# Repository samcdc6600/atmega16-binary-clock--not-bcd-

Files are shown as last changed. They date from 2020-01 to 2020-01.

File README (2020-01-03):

Note that the file "m16Adef.inc" is not of my own creation and the licensing of
this project does not apply to it. I am not aware of what it's license is.

We assemble simply by issuing the following command (where x.asm is the name of
our assembly file):
    avra x.asm
    
We flash our micro with the following command (this is assumming our flasher's
device file is ugen0.2 and hello.hex is the output of avra that we are
interested in):
   doas avrdude -p m16 -c usbasp -P/dev/ugen0.2 -U flash:w:hello.hex

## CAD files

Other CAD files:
main.obj

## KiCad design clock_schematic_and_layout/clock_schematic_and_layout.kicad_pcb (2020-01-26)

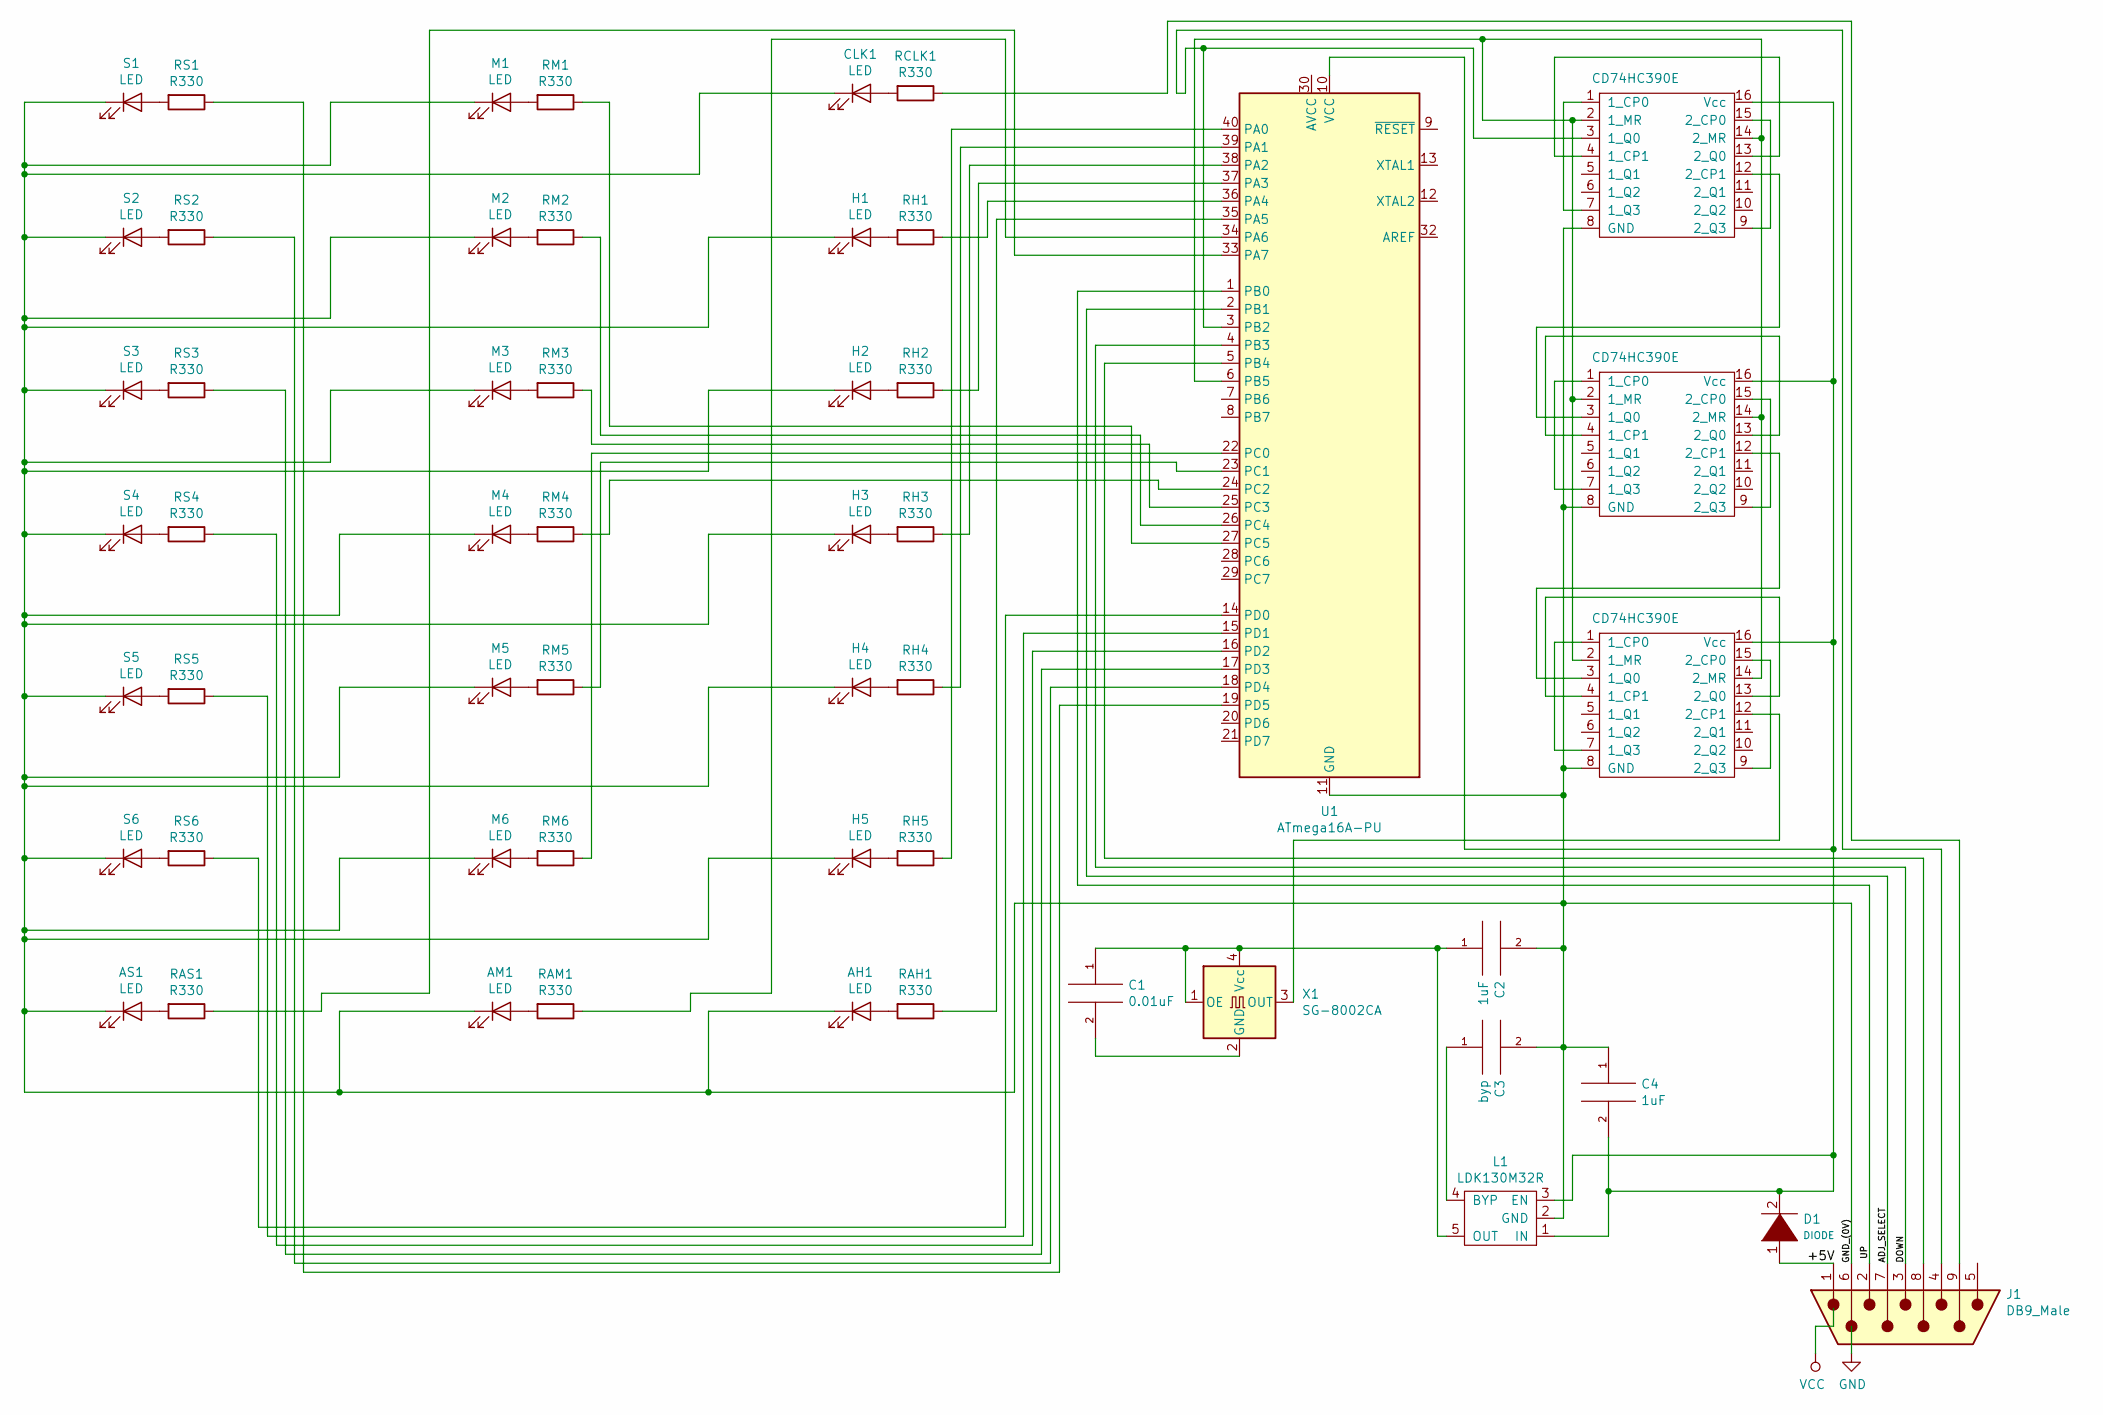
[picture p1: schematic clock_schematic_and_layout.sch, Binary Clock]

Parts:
AH1: LED; LED_D3.0mm_Horizontal_O1.27mm_Z2.0mm_Clear
AM1: LED; LED_D3.0mm_Horizontal_O1.27mm_Z2.0mm_Clear
AS1: LED; LED_D3.0mm_Horizontal_O1.27mm_Z2.0mm_Clear
C1: 0.01uF; Crystal_SMD_TXC_9HT11-2Pin_2.0x1.2mm_HandSoldering
C2, C4: 1uF; CP_Radial_D4.0mm_P2.00mm
C3: byp; CP_Radial_D4.0mm_P2.00mm
CD74HC390E1, CD74HC390E2, CD74HC390E3: CD74HC390E; DIP-16_W7.62mm_LongPads
CLK1: LED; LED_D3.0mm_Horizontal_O1.27mm_Z2.0mm_Clear
D1: DIODE; D_MELF-RM10_Universal_Handsoldering
H1, H2, H3, H4, H5: LED; LED_D3.0mm_Horizontal_O1.27mm_Z2.0mm_Clear
J1: DB9_Male; DSUB-9_Female_Horizontal_P2.77x2.84mm_EdgePinOffset7.70mm_H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
L1: LDK130M32R; TSOT-23-5_HandSoldering
M1, M2, M3, M4, M5, M6: LED; LED_D3.0mm_Horizontal_O1.27mm_Z2.0mm_Clear
RAH1: R330; R_Axial_DIN0207_L6.3mm_D2.5mm_P7.62mm_Horizontal
RAM1: R330; R_Axial_DIN0207_L6.3mm_D2.5mm_P7.62mm_Horizontal
RAS1: R330; R_Axial_DIN0207_L6.3mm_D2.5mm_P7.62mm_Horizontal
RCLK1: R330; R_Axial_DIN0207_L6.3mm_D2.5mm_P7.62mm_Horizontal
RH1, RH2, RH3, RH4, RH5: R330; R_Axial_DIN0207_L6.3mm_D2.5mm_P7.62mm_Horizontal
RM1, RM2, RM3, RM4, RM5, RM6: R330; R_Axial_DIN0207_L6.3mm_D2.5mm_P7.62mm_Horizontal
RS1, RS2, RS3, RS4, RS5, RS6: R330; R_Axial_DIN0207_L6.3mm_D2.5mm_P7.62mm_Horizontal
S1, S2, S3, S4, S5, S6: LED; LED_D3.0mm_Horizontal_O1.27mm_Z2.0mm_Clear
U1: ATmega16A-PU; DIP-40_W15.24mm
X1: SG-8002CA; Oscillator_SMD_SeikoEpson_SG8002CA-4Pin_7.0x5.0mm_HandSolde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

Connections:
/+5V: D1.1 (K), J1.1
/ADJ_SELECT: J1.7, U1.2 (PB1)
/DOWN: J1.3, U1.4 (PB3)
/GND_(0V): AH1.1 (K), AM1.1 (K), AS1.1 (K), C2.2, C3.2, C4.1, CD74HC390E1.8 (GND), CD74HC390E2.8 (GND), CD74HC390E3.8 (GND), CLK1.1 (K), H1.1 (K), H2.1 (K), H3.1 (K), H4.1 (K), H5.1 (K), J1.6, L1.2 (GND), M1.1 (K), M2.1 (K), M3.1 (K), M4.1 (K), M5.1 (K), M6.1 (K), S1.1 (K), S2.1 (K), S3.1 (K), S4.1 (K), S5.1 (K), S6.1 (K), U1.11 (GND), U1.31 (GND)
/UP: J1.2, U1.1 (PB0)
unnamed: AH1.2 (A), RAH1.2
unnamed: AM1.2 (A), RAM1.2
unnamed: AS1.2 (A), RAS1.2
unnamed: C1.1, C2.1, L1.5 (OUT), X1.1 (OE), X1.4 (Vcc)
unnamed: C1.2, X1.2 (GND)
unnamed: C3.1, L1.4 (BYP)
unnamed: C4.2, CD74HC390E1.16 (Vcc), CD74HC390E2.16 (Vcc), CD74HC390E3.16 (Vcc), D1.2 (A), L1.1 (IN), L1.3 (EN), U1.10 (VCC)
unnamed: CD74HC390E1.1 (1_CP0), CD74HC390E1.7 (1_Q3)
unnamed: CD74HC390E1.3 (1_Q0), J1.4, U1.3 (PB2)
unnamed: CD74HC390E1.12 (2_CP1), CD74HC390E2.3 (1_Q0)
unnamed: CD74HC390E1.4 (1_CP1), CD74HC390E1.13 (2_Q0)
unnamed: CD74HC390E1.2 (1_MR), CD74HC390E1.14 (2_MR), CD74HC390E2.2 (1_MR), CD74HC390E2.14 (2_MR), CD74HC390E3.2 (1_MR), CD74HC390E3.14 (2_MR), U1.6 (PB5)
unnamed: CD74HC390E1.9 (2_Q3), CD74HC390E1.15 (2_CP0)
unnamed: CD74HC390E2.1 (1_CP0), CD74HC390E2.7 (1_Q3)
unnamed: CD74HC390E2.12 (2_CP1), CD74HC390E3.3 (1_Q0)
unnamed: CD74HC390E2.4 (1_CP1), CD74HC390E2.13 (2_Q0)
unnamed: CD74HC390E2.9 (2_Q3), CD74HC390E2.15 (2_CP0)
unnamed: CD74HC390E3.1 (1_CP0), CD74HC390E3.7 (1_Q3)
unnamed: CD74HC390E3.12 (2_CP1), X1.3 (OUT)
unnamed: CD74HC390E3.4 (1_CP1), CD74HC390E3.13 (2_Q0)
unnamed: CD74HC390E3.9 (2_Q3), CD74HC390E3.15 (2_CP0)
unnamed: CLK1.2 (A), RCLK1.2
unnamed: H1.2 (A), RH1.2
unnamed: H2.2 (A), RH2.2
unnamed: H3.2 (A), RH3.2
unnamed: H4.2 (A), RH4.2
unnamed: H5.2 (A), RH5.2
unnamed: J1.8, U1.5 (PB4)
unnamed: J1.9, RCLK1.1
unnamed: M1.2 (A), RM1.2
unnamed: M2.2 (A), RM2.2
unnamed: M3.2 (A), RM3.2
unnamed: M4.2 (A), RM4.2
unnamed: M5.2 (A), RM5.2
unnamed: M6.2 (A), RM6.2
unnamed: RAH1.1, U1.35 (PA5)
unnamed: RAM1.1, U1.34 (PA6)
unnamed: RAS1.1, U1.33 (PA7)
unnamed: RH1.1, U1.36 (PA4)
unnamed: RH2.1, U1.37 (PA3)
unnamed: RH3.1, U1.38 (PA2)
unnamed: RH4.1, U1.39 (PA1)
unnamed: RH5.1, U1.40 (PA0)
unnamed: RM1.1, U1.27 (PC5)
unnamed: RM2.1, U1.26 (PC4)
unnamed: RM3.1, U1.25 (PC3)
unnamed: RM4.1, U1.24 (PC2)
unnamed: RM5.1, U1.23 (PC1)
unnamed: RM6.1, U1.22 (PC0)
unnamed: RS1.1, U1.19 (PD5)
unnamed: RS1.2, S1.2 (A)
unnamed: RS2.1, U1.18 (PD4)
unnamed: RS2.2, S2.2 (A)
unnamed: RS3.1, U1.17 (PD3)
unnamed: RS3.2, S3.2 (A)
unnamed: RS4.1, U1.16 (PD2)
unnamed: RS4.2, S4.2 (A)
unnamed: RS5.1, U1.15 (PD1)
unnamed: RS5.2, S5.2 (A)
unnamed: RS6.1, U1.14 (PD0)
unnamed: RS6.2, S6.2 (A)

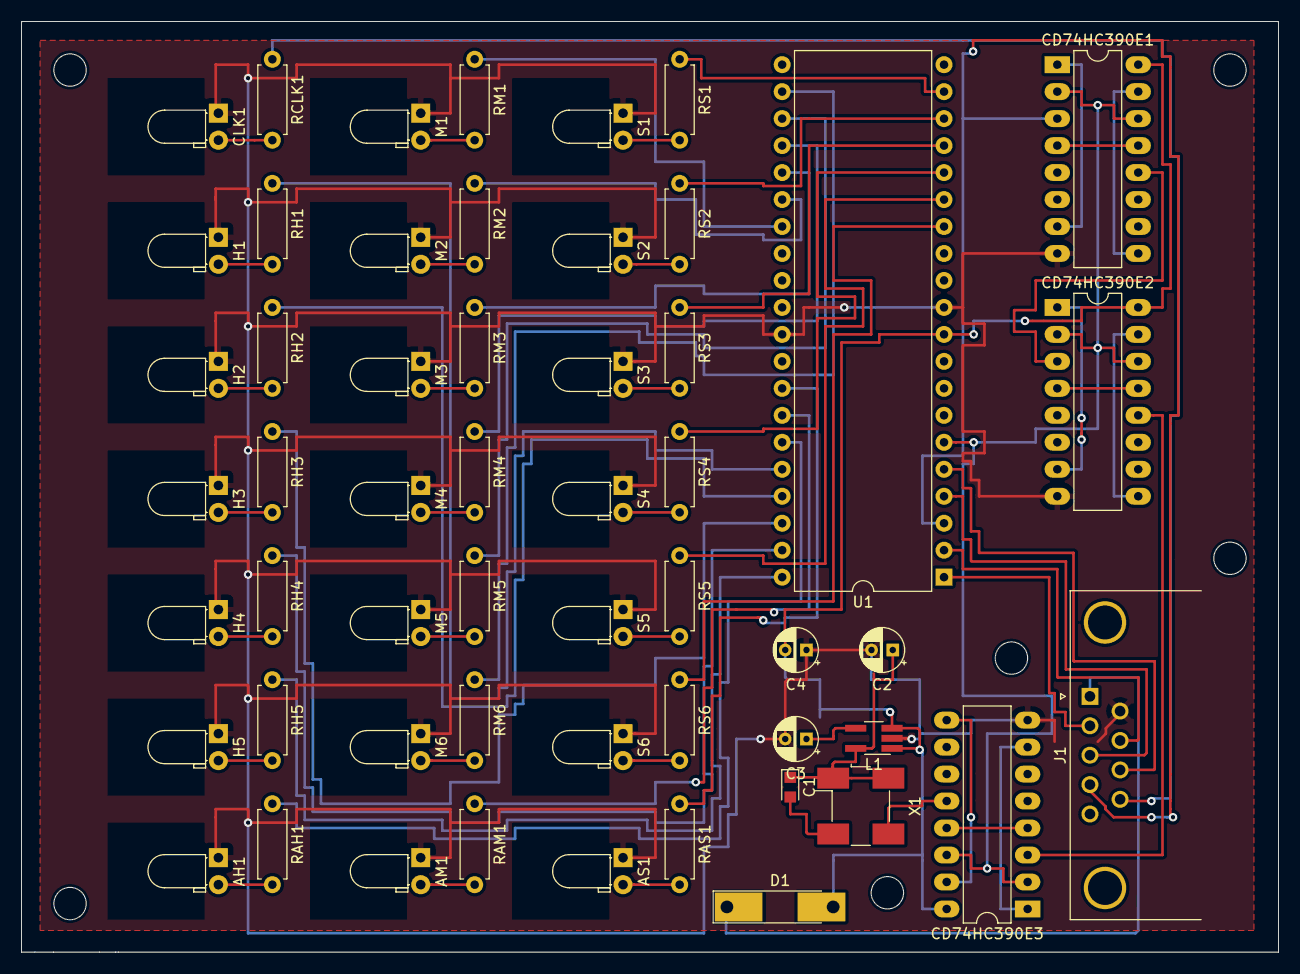
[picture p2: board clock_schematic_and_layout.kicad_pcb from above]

Board: 2 copper layers, 118.4 x 87.6 mm, 54 parts (0 on the bottom side), 66 nets.

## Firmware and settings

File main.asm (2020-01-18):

	;; for AVR: atmega16 (no external occilator used for the clock.)
	;; We are running at 1MHz...

	
	.nolist			; Don't include in the .lst file if we ask the
				; assembler to generate one.
	.include "./include/m16Adef.inc"


	;; =====================================================================
	;; Definitions
	.def	secondCount = r17
	.def	minuteCount = r18
	.def	hourCount = r19
	.def	currentlyAdjusting = r20
	;; Constants
 	.equ	minAndHour = 0b00111100
 	.equ	day = 0b00011000
	.equ	maxUnsignedByte = 0b11111111
	;; We set all pins for ports PA, PC and PD to outputs so we dont have to
	;; worry about pull ups to save power on the pins we are not actually
	;; using, that is assuming it works like that :)
	.equ	ddrSecondPins = 0b11111111	; Pins PD0 - PD7 (PD0 - PD5 used)
	.equ	ddrMinutePins = 0b11111111 ; Pins PC7 - PC0 (PC5 - PC0 used)
	;; Pins PA0 - PA7 (PA0 - PA4 used for hours and PA5 - PA7 used for
	;; adjust LED Indicator Pins)
	.equ	ddrHourAndAdjustLEDIndicatorPins = 0b11111111
	;; For changing the time. Pins PB0 - PB7 (PB0, PB1, PB3 and PB4 used as
	.equ	ddrAdjustPins = 0b00100000 ; input and PB5 used as output
	;; Enable the pullups for PB (except for PB2 (as it is active high) and
	;; PB5 (we set this low as it is used to toggle master reset 1 (1mr) on
	;; the decade counter the ocsilator is connected to (it is active high))
	.equ	adjustPinsPullups = 0b11011011 ; ocsilator)
	.equ	adjustPinsPullupsMR1High = 0b11111011
	;; Pin outs for adjust LEDs
	.equ	adjustSecondsLEDIndicatorPin = 0b10000000
	.equ	adjustMinutesLEDIndicatorPin = 0b01000000
	.equ	adjustHoursLEDIndicatorPin = 0b00100000
	;; To dissable (mask out) adjust LEDS
	.equ	noAdjustLEDs = 0b00011111
	;; To mask out PB2 (INT2) and PA5 (1mr)
	.equ	noInt2Or1Mr = 0b11011011
	;; To enable int 2 (pin PB2)
	.equ	int2En = 0b00100000
	;; Adjust input masks
	.equ	adjustUpPin = 0b11011010
	.equ	adjustTimeUnitSelection = 0b11011001
	.equ	adjustDown = 0b11010011
	.equ	dissableAdjust = 0b11001011
	;; These variables should be > 0
	.equ	debounceFactor0 = 0b11111111
	.equ	debounceFactor1 = 0b11111000
	.equ	debounceFactor2 = 0b00000001

	
	;; =====================================================================
	;; Interrupt vector
	jmp   RESET	; Reset Handler
	jmp   EXT_INT0	; IRQ0 Handler
	jmp   EXT_INT1	; IRQ1 Handler
	jmp   TIM2_COMP	; Timer2 Compare Handler
	jmp   TIM2_OVF	; Timer2 Overflow Handler
	jmp   TIM1_CAPT	; Timer1 Capture Handler
	jmp   TIM1_COMPA	; Timer1 CompareA Handler
	jmp   TIM1_COMPB	; Timer1 CompareB Handler
	jmp   TIM1_OVF	; Timer1 Overflow Handler
	jmp   TIM0_OVF	; Timer0 Overflow Handler
	jmp   SPI_STC	; SPI Transfer Complete Handler
	jmp   USART_RXC	; USART RX Complete Handler
	jmp   USART_UDRE	; UDR Empty Handler
	jmp   USART_TXC	; USART TX Complete Handler
	jmp   ADC	; ADC Conversion Complete Handler
	jmp   EE_RDY	; EEPROM Ready Handler
	jmp   ANA_COMP	; Analog Comparator Handler
	jmp   TWSI	; Two-wire Serial Interface Handler
	jmp   EXT_INT2	; IRQ2 Handler
	jmp   TIM0_COMP	; Timer0 Compare Handler
	jmp   SPM_RDY	; Store Program Memory Ready Handler;

	
RESET:				  ;=============================================
	ldi	r16, high(RAMEND)	; Main program start
	out	SPH, r16	; Set Stack Pointer to top of RAM
	ldi	r16, low(RAMEND)
	out	SPL, r16
	; Stack set up now perform the remaining initialisation tasks
	call	INIT
CONTINUE:
	call	ADJUST
	call	KEEP_TIME
	call	DISPLAY_TIME
	rjmp	CONTINUE


INIT:				;===============================================
	call	DISABLE_JTAG
	clr	secondCount	; Clear the regs we store time in
	clr	minuteCount
	clr	hourCount

	ldi	r16, low(ddrSecondPins)
	out	DDRD, r16	; Set the Data Direction Register for Port D (seconds)
	out	PortD, secondCount ; Set second pins low

	ldi	r16, low(ddrMinutePins)
	out	DDRC, r16	; Set the Data Direction Register for port C (minutes)
	out	PortC, minuteCount ; Set minute pins low

	; Port A is shared between hours and the time adjustment indicator LEDs
	ldi	r16, low(ddrHourAndAdjustLEDIndicatorPins)
	out	DDRA, r16	; Set the Data Direction Register for port A (hours)
	out	PortA, hourCount	; Set hour pins low

	ldi	r16, low(ddrAdjustPins)
	;; Set the Data Direction Register for Port B (time adjustment controls
	;; and time signal)
	out	DDRB, r16	; Also note that PB2 is used for our time signal
	ldi	r16, low(adjustPinsPullups)
	; Set pull up's high (except for PB2 (time signal) which is active high)
	out	PortB, r16
	
	ldi	r16, low(int2En)
	out	GICR, r16	; Set external interrupt 2 to be enabled
	sei			; Enable interrupts
	ret


	;; DISABLE_JTAG dissables the JTAG interface (PC7 - PC2) in software.
	;; This allows the use of the PC7 - PC2 pins as general IO while still
	;; allowing the chip to be programmed as we have not set any fuses.
	;; The manual says to set the JTD bit (bit 7 according to the manual (pg
	;; 236) but that does not seem to work.) Post #3 on this site:
	;; https://www.avrfreaks.net/forum/how-disable-jtag-c
	;; said to use 0x80 and that does work. From the manual "In order to
	;; avoid unintentional disabling or enabling of the JTAG interface, a
	;; timed sequence must be followed when changing this bit: The
	;; application software must write this bit to the desired value twice
	;; within four cycles to change its value."
DISABLE_JTAG:			;===============================================
	ldi	r16, 0x80
	out	MCUCSR, r16
	out	MCUCSR, r16
	ret


	;; Handle time adjustment
ADJUST:				;===============================================
	;; Note that we only check for 1 pin being high at a time. Pressing
	;; more then one button simultaniously will not activate time
	;; adjustment, that is if you can do it fast enough ;)
	call	READ_ADJUST_PINS
	cpi	r16, low(adjustUpPin)
	breq	PIN_HIGH
	cpi	r16, low(adjustTimeUnitSelection)
	breq	PIN_HIGH
	cpi	r16, low(adjustDown)
	breq	PIN_HIGH
	rjmp	PIN_LOW
PIN_HIGH:
	call	ADJUSTING_DELAY
PIN_LOW:
	ret


READ_ADJUST_PINS:		;===============================================
	in	r16, PinB
	andi	r16, noInt2Or1Mr
	ret


	;; An adjustment input has gone high. Alow time for adjustment and
	;; Call adjust proper
ADJUSTING_DELAY:		;===============================================
 	cli			; Dissable interrupts
	;; We do this here and not after "brne	WAIT_FOR_USER_INPUT" because
	;; interrups seem to be re-enabled (when PB0 is low) randomly after
	;; the PB0 pin is held low or strobed enough when adjusting minutes,
	;; causing the seconds count to increment. We cannot figure it out.
	;; We think it may even be an electrical problem although we hope not.
	;; It seems to take different times for different chips :/
	;; Enable 1MR on decade counter
	ldi	r16, low(adjustPinsPullupsMR1High)
	out	PortB, r16
	;; Always start on minutes
	ldi	currentlyAdjusting, adjustMinutesLEDIndicatorPin
	call	SET_ADJUSTING_LEDS
	call	DEBOUNCE
WAIT_FOR_USER_INPUT:
	call	ADJUSTING_PROPER
	cpi	r16, low(dissableAdjust)
	brne	WAIT_FOR_USER_INPUT
	;; Int2 is triggered when the signal goes low, it starts high when reset
	;; and stays there for 1/2 of a second. So we add roughly half a seconds
	;; worth of debounce before strobing 1MR and enabling interrupts.
	;; With	debounceFactor0 = 0b11111111, debounceFactor1 = 0b11111000 and
	;; debounceFactor2 = 0b00000001 we have:
	;; (1,000,000 / (256 * 248 * 1)) / 2, which equals 7.8. So we call
	;; debounce 8 times.
	call	DEBOUNCE
	call	DEBOUNCE
	call	DEBOUNCE
	call	DEBOUNCE
	call	DEBOUNCE
	call	DEBOUNCE
	call	DEBOUNCE
	call	DEBOUNCE
	;; allow ample time for the pin to go high.
	sei			; Enable interrupts
	ldi	r16, low(adjustPinsPullups) ; Dissable 1MR on decade counter
	out	PortB, r16
	clr	currentlyAdjusting
	ret


	;; Check adjustment inputs and adjust time accordingly
ADJUSTING_PROPER:		;===============================================
	call	READ_ADJUST_PINS
	cpi	r16, low(dissableAdjust)
	;; Return to ADJUSTING_DELAY if dissableAdjust is pressed
	;; ADJUSTING_DELAY will re-enable interrupts, strobe the crystal enable
	breq	RET_FROM_ADJUSTING_PROPER ; off and then on again and then exit
	cpi	r16, low(adjustTimeUnitSelection)
	breq	CHANGE_TIME_SELECTION
	cpi	r16, low(adjustUpPin)
	breq	ADJUST_TIME_UP
	cpi	r16, low(adjustDown)
	breq	ADJUST_TIME_DOWN
	rjmp	RET_FROM_ADJUSTING_PROPER
	
CHANGE_TIME_SELECTION:
	call	CHANGE_TIME_SELECTION_PROPER
	call	DEBOUNCE
	rjmp	SET_ADJUSTING_LEDS_ANDRET_FROM_ADJUSTING_PROPER
ADJUST_TIME_UP:
	call	ADJUST_TIME_UP_PROPER
	call	DEBOUNCE
	rjmp	SET_ADJUSTING_LEDS_ANDRET_FROM_ADJUSTING_PROPER
ADJUST_TIME_DOWN:
	call	ADJUST_TIME_DOWN_PROPER
	call	DEBOUNCE

SET_ADJUSTING_LEDS_ANDRET_FROM_ADJUSTING_PROPER:
	call	DISPLAY_TIME
	call	SET_ADJUSTING_LEDS
	
RET_FROM_ADJUSTING_PROPER:
	ret


CHANGE_TIME_SELECTION_PROPER:	;===============================================
	cpi	currentlyAdjusting, low(adjustHoursLEDIndicatorPin)
	breq	CYCLE_BACK_AROUND
	ror	currentlyAdjusting
	rjmp	RET_FROM_CHANGE_TIME_SELECTION_PROPER	
CYCLE_BACK_AROUND:
	ldi	currentlyAdjusting, low(adjustSecondsLEDIndicatorPin)
RET_FROM_CHANGE_TIME_SELECTION_PROPER:
	ret


ADJUST_TIME_UP_PROPER:		;===============================================
	cpi	currentlyAdjusting, low(adjustSecondsLEDIndicatorPin)
	breq	UP_SECONDS
	cpi	currentlyAdjusting, low(adjustMinutesLEDIndicatorPin)
	breq	UP_MINUTES
	cpi	currentlyAdjusting, low(adjustHoursLEDIndicatorPin)
	breq	UP_HOURS
	rjmp	RET_ADJUST_TIME_UP_PROPER
	
UP_SECONDS:
	inc	secondCount
	cpi	secondCount, low(minAndHour)
	brlo	RET_ADJUST_TIME_UP_PROPER
	clr	secondCount
	rjmp	RET_ADJUST_TIME_UP_PROPER

UP_MINUTES:
	inc	minuteCount
	cpi	minuteCount, low(minAndHour)
	brlo	RET_ADJUST_TIME_UP_PROPER
	clr	minuteCount
	rjmp	RET_ADJUST_TIME_UP_PROPER
	
UP_HOURS:
	inc	hourCount
	cpi	hourCount, low(day)
	brlo	RET_ADJUST_TIME_UP_PROPER
	clr	hourCount
	
RET_ADJUST_TIME_UP_PROPER:
	ret


ADJUST_TIME_DOWN_PROPER:	;===============================================
	cpi	currentlyAdjusting, low(adjustSecondsLEDIndicatorPin)
	breq	DOWN_SECONDS
	cpi	currentlyAdjusting, low(adjustMinutesLEDIndicatorPin)
	breq	DOWN_MINUTES
	cpi	currentlyAdjusting, low(adjustHoursLEDIndicatorPin)
	breq	DOWN_HOURS
	rjmp	RET_ADJUST_TIME_DOWN_PROPER

DOWN_SECONDS:
	dec	secondCount
	cpi	secondCount, low(maxUnsignedByte)
	brne	RET_ADJUST_TIME_DOWN_PROPER
	ldi	secondCount, low(minAndHour)
	dec	secondCount
	rjmp	RET_ADJUST_TIME_DOWN_PROPER
	
DOWN_MINUTES:
	dec	minuteCount
	cpi	minuteCount, low(maxUnsignedByte)
	brne	RET_ADJUST_TIME_DOWN_PROPER
	ldi	minuteCount, low(minAndHour)
	dec	minuteCount
	rjmp	RET_ADJUST_TIME_DOWN_PROPER
	
DOWN_HOURS:
	dec	hourCount
	cpi	hourCount, low(maxUnsignedByte)
	brne	RET_ADJUST_TIME_DOWN_PROPER
	ldi	hourCount, low(day)
	dec	hourCount

RET_ADJUST_TIME_DOWN_PROPER:
	ret


SET_ADJUSTING_LEDS:		;===============================================
	push	r16
	clr	r16
	mov	r16, hourCount
	or	r16, currentlyAdjusting
	out	PortA,	r16
	pop	r16
	ret


DEBOUNCE:			;===============================================
	clr	r31
	clr	r30
	clr	r29
DEBOUNCE_LOOP_0_START:
	inc	r31
	
DEBOUNCE_LOOP_1_START:
	inc	r30
	
DEBOUNCE_LOOP_2_START:
	inc	r29
	
	cpi	r29, low(debounceFactor0)
	brne	DEBOUNCE_LOOP_2_START

	cpi	r30, low(debounceFactor1)
	brne	DEBOUNCE_LOOP_1_START
	
	cpi	r31, low(debounceFactor2)
	brne	DEBOUNCE_LOOP_0_START
	ret


KEEP_TIME:		      ;=================================================
	cpi	secondCount, low(minAndHour) ; Have we counted 60 seconds?
	brlo	SUB_UNIT
	clr	secondCount	; Start counting the next minute
	inc	minuteCount
	
	cpi	minuteCount, low(minAndHour) ; Have we counted an hour?
	brlo	SUB_UNIT
	clr	minuteCount	; start counting the next hour
	inc	hourCount

	cpi	hourCount, low(day) ; Have we counted a day?
	brlo	SUB_UNIT
	clr	hourCount
SUB_UNIT:
	ret

	
DISPLAY_TIME:			;===============================================
	out	PortD, secondCount
	out	PortC, minuteCount
	out	PortA, hourCount
	ret


EXT_INT0:	; IRQ0 Handler
EXT_INT1:	; IRQ1 Handler
TIM2_COMP:	; Timer2 Compare Handler
TIM2_OVF:	; Timer2 Overflow Handler
TIM1_CAPT:	; Timer1 Capture Handler
TIM1_COMPA:	; Timer1 CompareA Handler
TIM1_COMPB:	; Timer1 CompareB Handler
TIM1_OVF:	; Timer1 Overflow Handler
TIM0_OVF:	; Timer0 Overflow Handler
SPI_STC:	; SPI Transfer Complete Handler
USART_RXC:	; USART RX Complete Handler
USART_UDRE:	; UDR Empty Handler
USART_TXC:	; USART TX Complete Handler
ADC:		; ADC Conversion Complete Handler
EE_RDY:		; EEPROM Ready Handler
ANA_COMP:	; Analog Comparator Handler
TWSI:		; Two-wire Serial Interface Handler
EXT_INT2:	; IRQ2 Handler
				; Note that another second has passed
	inc	secondCount	; Time flies :O :'(
	reti
TIM0_COMP:	; Timer0 Compare Handler
SPM_RDY:	; Store Program Memory Ready Handler;

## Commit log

2020-01-07 We have implemented the basic clock functionality. Now we need to implement the time adjustment functionality.
    [main.obj]
2020-01-09 We have implemented the time chaning functionality to some extent. It is not fully functional yet however. The code from this commit should not be used as it.
    [main.obj]
2020-01-09 Fixed a couple of bugs. There are still a couple (that I know of) that need fixing however.
    [main.obj]
2020-01-11 We have fixed a couple of bugs but have also introduced a regression regarding the automated updating of time. We will be using the stack from now on to provide more isolation for our sub rutines. We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
    [main.obj]
2020-01-13 Fixed bug with hourCount being corrupted with currentlyAdjusting value.
    [main.obj]
2020-01-13 removed some stuff to ensure merging is easier
    [main.obj]
2020-01-13 "There is a bit of oddness when exiting the adjusting mode in terms of the seconds LEDs changing faster then they should. However we thing that the overall timming is correct. There is a very strange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
    [main.obj]
2020-01-13 We have added a workaround for the terrible functionality breaking bug described in the last commit. Although we wish we could figour out the root cause :'(. Our fix involves enabling 1MR on our coun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
    [main.obj]
2020-01-14 Fixed error in commente and added partialy finished schematic
    [clock_schematic_and_layout.kicad_pcb, clock_schematic_and_layout.sch]
2020-01-14 Made further adjustment to comment.
    [clock_schematic_and_layout.sch]
2020-01-18 Removed erronious jump from ADJUST_TIME_DOWN_PROPER sub routine (also have done more work on schematics)
    [clock_schematic_and_layout.sch]
2020-01-22 We have done some more work on the schematics and stuff
    [main.obj]
2020-01-26 Finished schematic and PCB layout. Haven't properly double checked the schematic though :'( (can't be bothered haha.)
    [backup.kicad_pcb, backup10.kicad_pcb, backup11.kicad_pcb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]
